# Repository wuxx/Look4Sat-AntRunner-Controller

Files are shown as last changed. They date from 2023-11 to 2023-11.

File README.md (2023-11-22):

# Look4Sat-AntRunner-Controller
 * [Introduce](#introduce)
 * [How to Use](#how-to-use)
 * [How to Compile](#how-to-compile)
 * [Rerfernce](#reference)

## Introduce
This project works as a component of my [AntRunner](https://github.com/wuxx/AntRunner) project to control my rotator wirelessly through the Look4Sat. Of course, if you have your own rotator that needs wireless control, this project should be helpful.

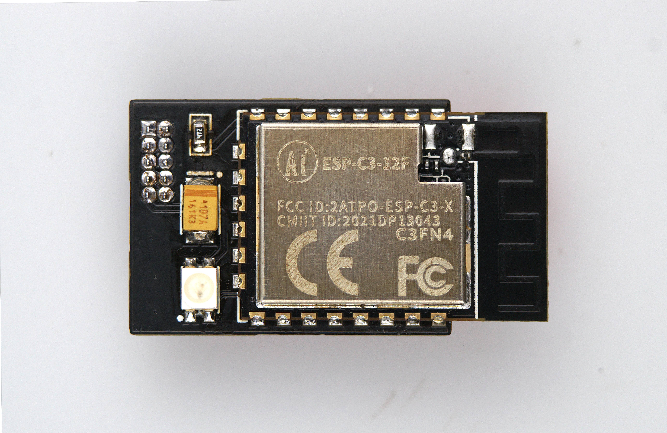
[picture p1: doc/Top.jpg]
top

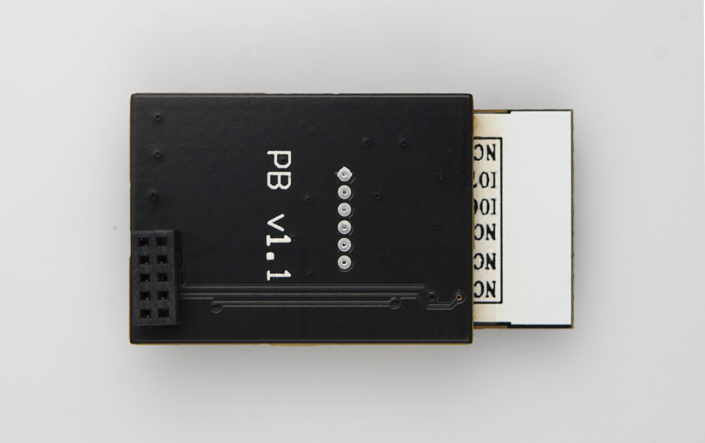
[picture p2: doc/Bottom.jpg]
bottom

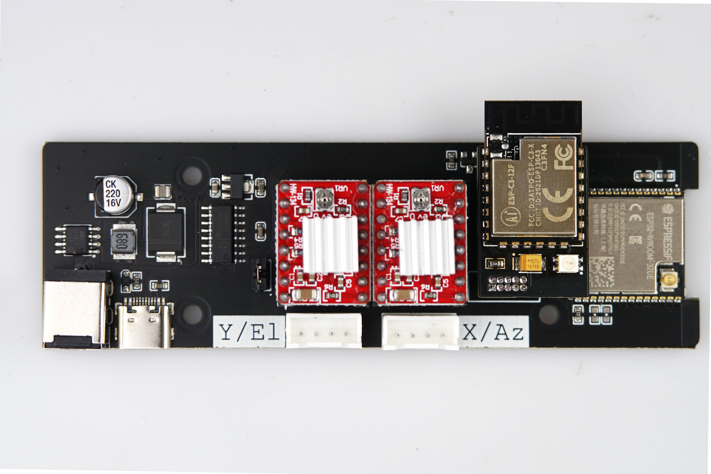
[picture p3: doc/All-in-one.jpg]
all-in-one


## How to Use

### Config the WiFi

Plug in the module on the AntRunner control board. After powering, a wifi hotspot called esp32 will appear. Click it to connect to this wifi hotspot (no password required).  
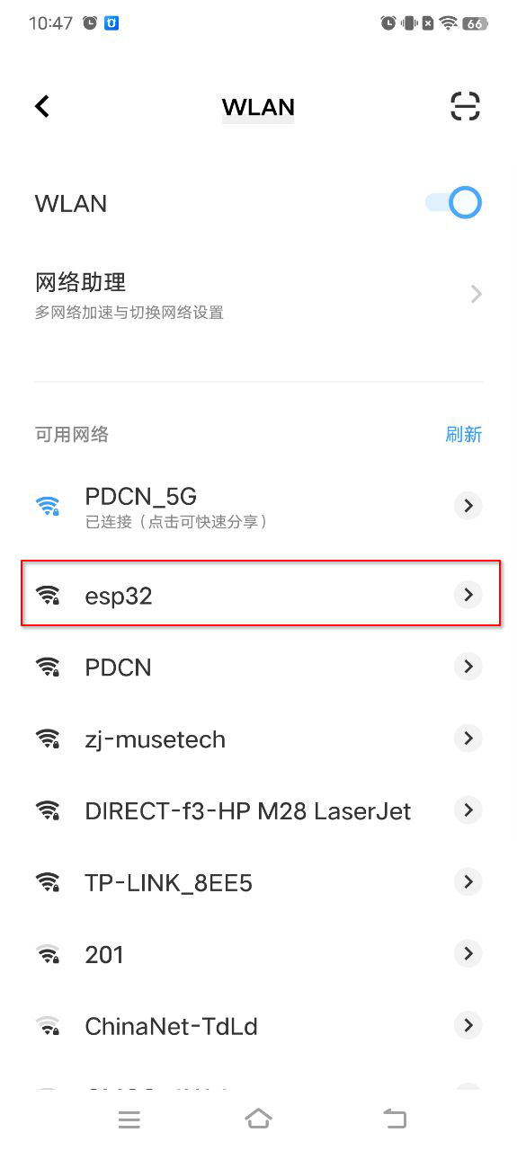
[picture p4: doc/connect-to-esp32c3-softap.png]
connect-to-esp32c3-softap


Then enter 10.10.10.1 in the browser to enter the operation background, select your wifi AP to connect. then the module will connect it in STA mode. After the connection is completed, you need to get the IP address, get it in the background of your WiFi AP or check the module's serial port output log.  
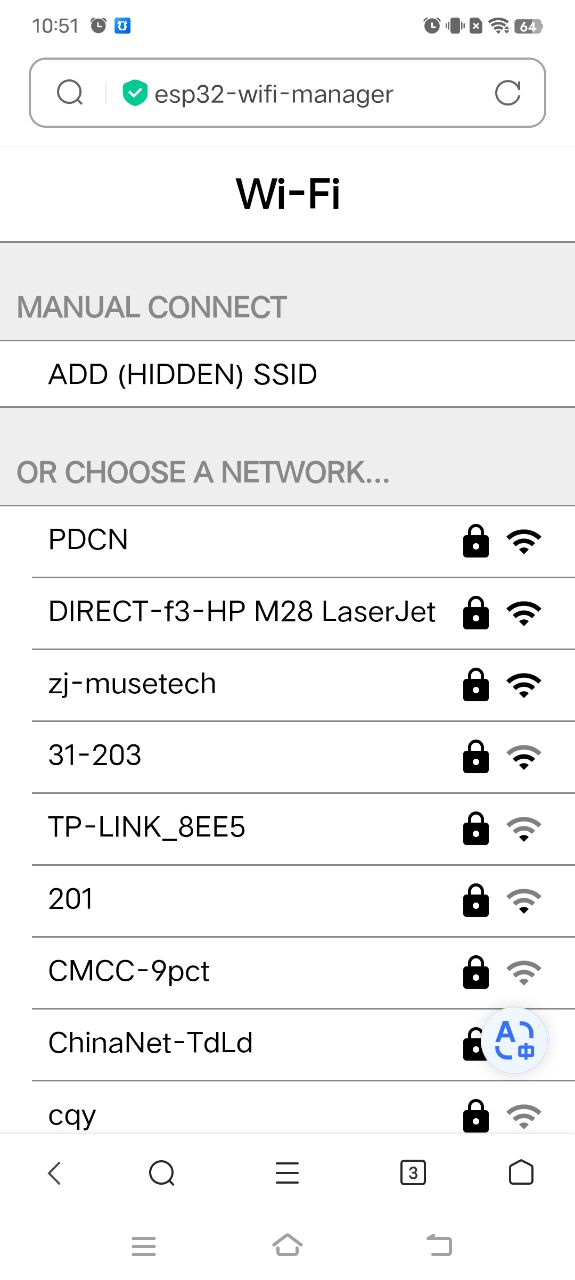
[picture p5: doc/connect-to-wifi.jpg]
connect-to-wifi


### Config the Look4Sat 

Open the configuration interface of Look4Sat, just fill in the IP address of module, and then the entire system can start working.   
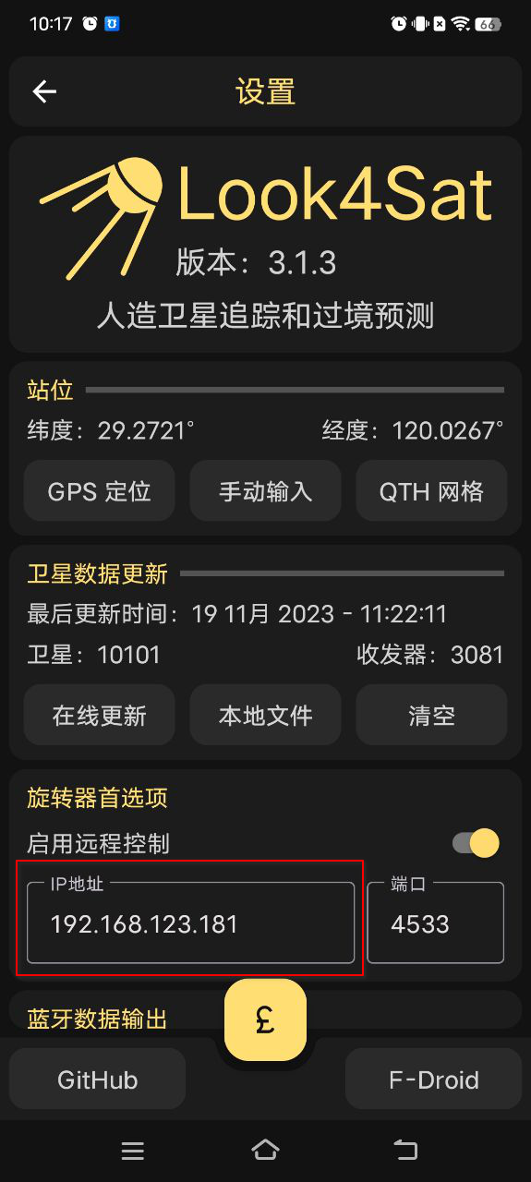
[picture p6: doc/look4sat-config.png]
look4sat-config


You can get the status of the current module by checking the LED lights. The details are as follows  

#### LED Status
LED | Description
---|---
Red light blink slowly | Connecting to wifi
Blue light always on| WiFi is connected
Green light always on | A connection has been established with Look4Sat
Green light blink quickly | Look4Sat is sending control commands

### Look4Sat Usage

The use of look4sat is very simple, just select a satellite entry and enter, look4sat will start sending control commands to the controller.  
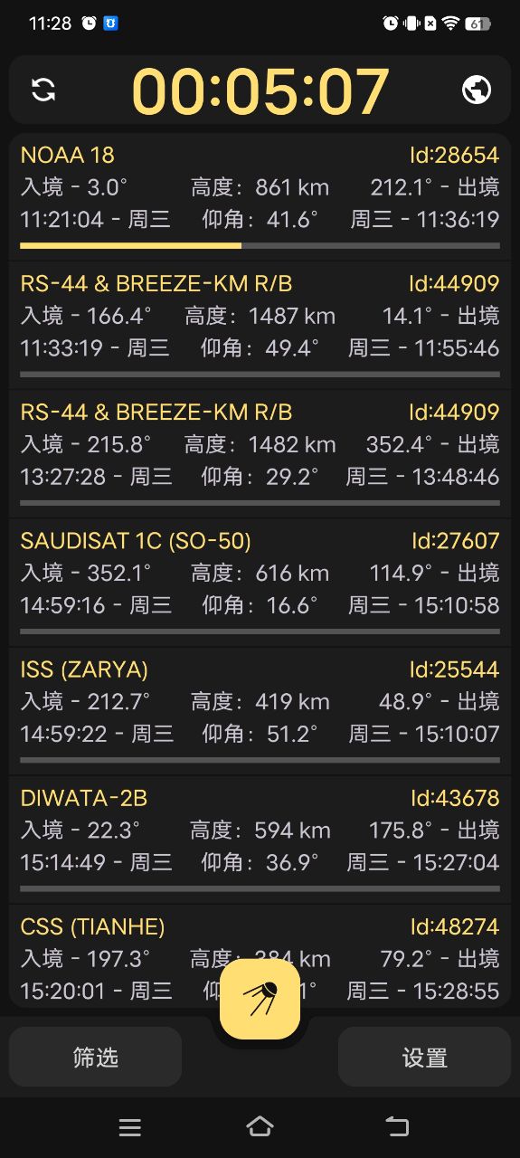
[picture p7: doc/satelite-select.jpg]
satelite-select

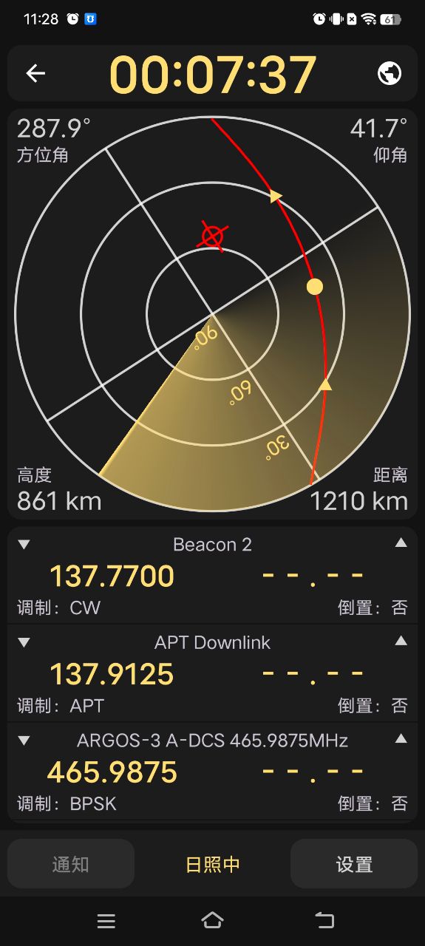
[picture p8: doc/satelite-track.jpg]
satelite-track


## How to Compile
the source code is compiled under esp-idf v5.1
```
$cd Look4Sat-AntRunner-Controller/software/
$cd ~/esp-idf && . ./export.sh && cd -
$idf.py set-target esp32c3
$idf.py build
$idf.py flash monitor
```

## Reference
- AntRunner (https://github.com/wuxx/AntRunner) 
- Look4Sat (https://github.com/rt-bishop/Look4Sat)

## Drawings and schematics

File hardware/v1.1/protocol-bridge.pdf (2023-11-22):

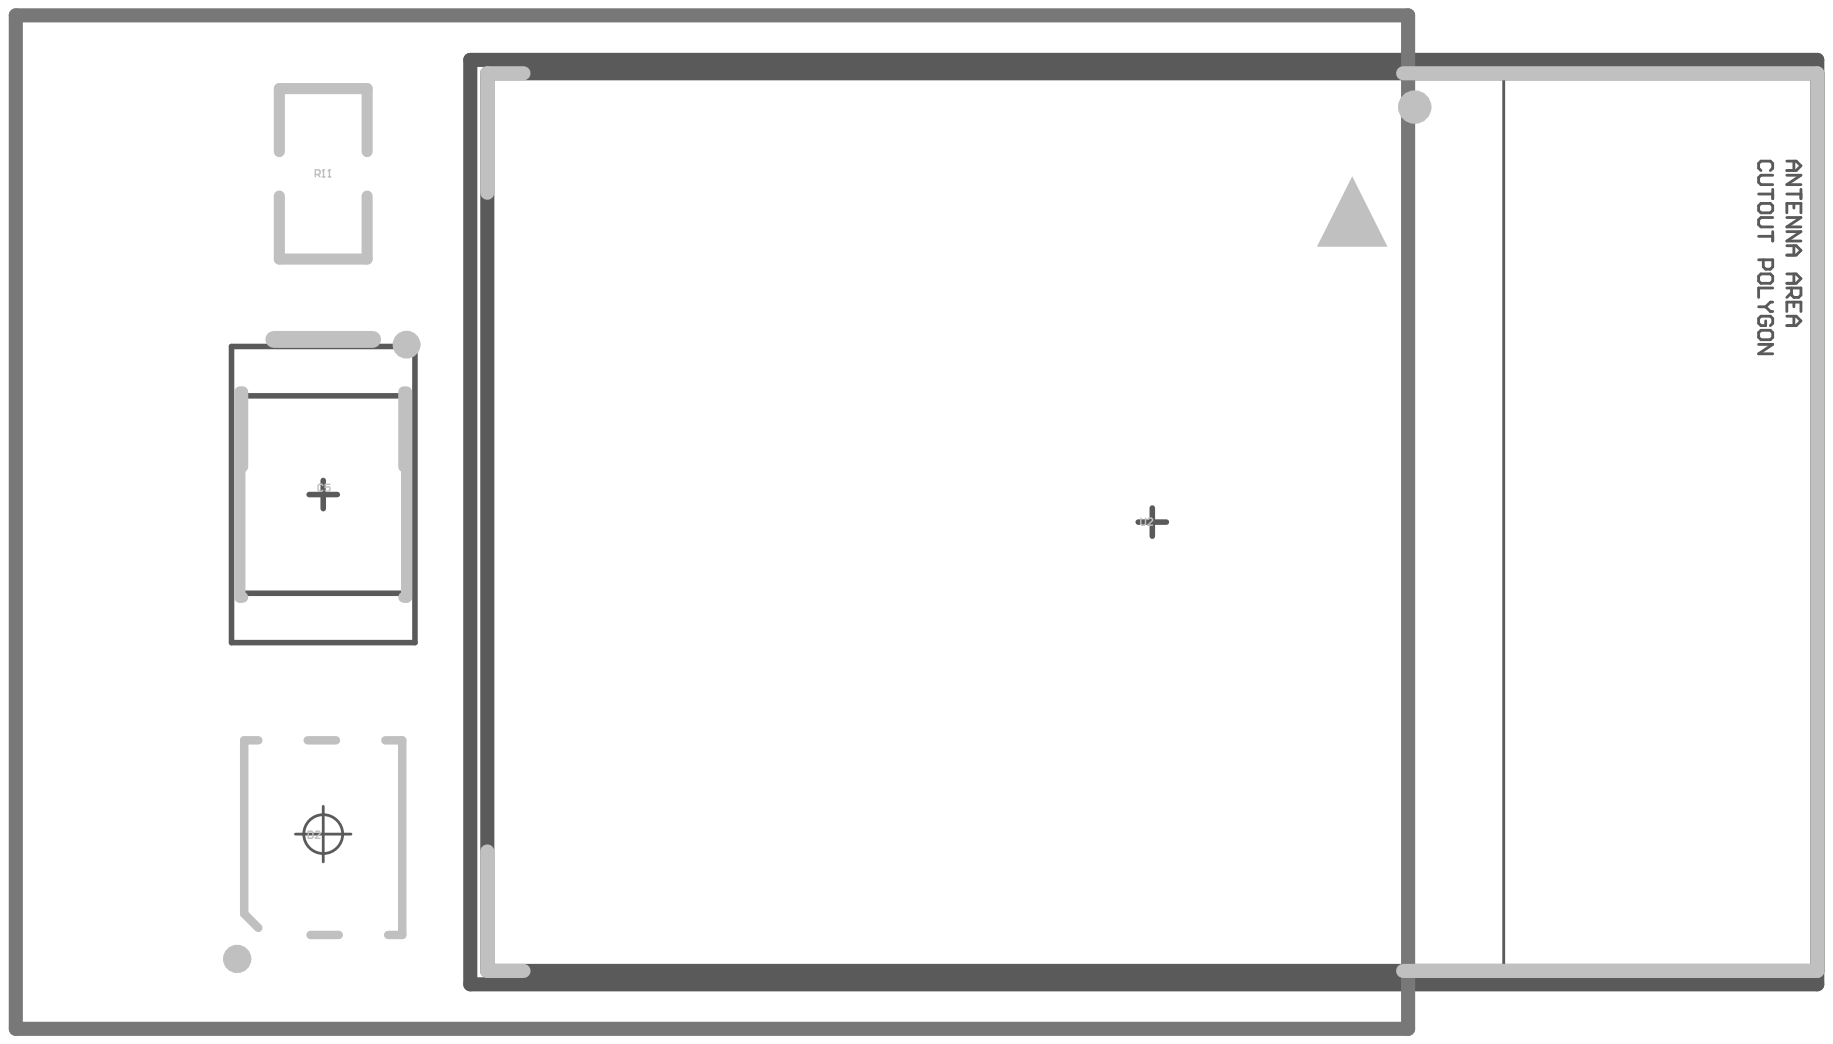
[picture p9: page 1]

Value | Comment | Designator | Footprint | Description | Quantity
| | J5 | HEADER_1.27_S MT_6x1 | Header, 4-Pin | 1
| 100uF | C5 | SMT_C_Tantalum _B | Capacitor, SM Tantalum; Body 3.5 x 2.8 mm (LxW typ) | 1
| ESP_C3_12F | U2 | ESP-C3-12F | ESP-12 Wi-Fi Module by AI-Thinker | 1
| Header 5X2 | J1 | HEAD_1.27_5x2 | Header, 5-Pin, Dual row | 1
| WS2812B | D2 | LED 3528-4Pin | | 1
4.7K | 4.7K | R11 | 0603_R | Resistor | 1

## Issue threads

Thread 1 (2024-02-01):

ESP32 download code

Montilien, 2024-02-01:
Hi,
Congratulations for your very nice work.
So I am familiar to load code to ESP32 using Arduino IDE but I not with ESP tools.
Please, can you write a step by step code downloading tutorial please?
An other problem for me, on module picture I can see 2 ESP32's modules. I don't understand why two esp32 are necessary to the rotator work?
Thanks for your response
Regards - F1FHK

Cyfarw9dd, 2024-08-07:
Hi,
This is BG2FZM, about load code using Arduino IDE. I'm afraid that this repository can only can run and flash on the esp-idf, which is a framework designed for the ESP chips for IOT functions, also more than that.
You can checkout this [tutorial](https://docs.espressif.com/projects/esp-idf/en/v5.3/esp32/get-started/index.html#installation) for further information. I recommend that you can use the vscode extension for the esp-idf and developing, which is more friendly and useful.
About the two chips, one is use for create a AP to let the other one and the mobile phone to check in, the other one running a tcp server to recviving the data from the Look4sat.
Hope it is useful
BG2FZM

wuxx, 2024-08-09:
Yes, in fact, one ESP chip can do all the work, but I don't want to modify the source code in GRBL, because the workload of modification may be relatively large, so this is a lazy solution

Cyfarw9dd, 2024-08-09:
maybe I will try，I've seen a stepper motor example using with DRV8825, providing by the esp idf offical example code. I currently try to work out this figure, still need more time XD.

> Yes, in fact, one ESP chip can do all the work, but I don't want to modify the source code in GRBL, because the workload of modification may be relatively large, so this is a lazy solution，may also be more flexible, because you can modify the source code yourself to adapt to other host software, and the source code will be simpler.

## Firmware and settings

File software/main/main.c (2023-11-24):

/* BSD Socket API Example

   This example code is in the Public Domain (or CC0 licensed, at your option.)

   Unless required by applicable law or agreed to in writing, this
   software is distributed on an "AS IS" BASIS, WITHOUT WARRANTIES OR
   CONDITIONS OF ANY KIND, either express or implied.
*/
#include <string.h>
#include <sys/param.h>
#include "freertos/FreeRTOS.h"
#include "freertos/task.h"
#include "esp_system.h"
#include "esp_wifi.h"
#include "esp_event.h"
#include "esp_log.h"
#include "nvs_flash.h"
#include "esp_netif.h"
#include <esp_ota_ops.h>
#include "esp_timer.h"

#include "esp_console.h"
#include "cmd_system.h"
#include "cmd_wifi.h"
#include "cmd_nvs.h"


//#include "protocol_examples_common.h"

#include "lwip/err.h"
#include "lwip/sockets.h"
#include "lwip/sys.h"
#include <lwip/netdb.h>

#include "wifi_manager.h"
#include "http_app.h"

#include "led_strip.h"

#include "driver/uart.h"

enum SYS_STATUS_E {

    WIFI_INIT = 0,
    WIFI_LOST,

    WIFI_CONNECTED,
    WIFI_IDLE,

    LOOK4SAT_CONNECTED,
    LOOK4SAT_IDLE,
    LOOK4SAT_XFER,
};

static uint32_t sys_status = WIFI_INIT;

int64_t last_xfer_systime = 0;
int64_t curr_systime = 0;

#define UART1_TXD    (0)
#define UART1_RXD    (1)
#define UART1_RTS    (UART_PIN_NO_CHANGE)
#define UART1_CTS    (UART_PIN_NO_CHANGE)
#define UART1_PORT_NUM      (1)
#define UART1_BAUD_RATE     (115200)

#define SERVER_PORT                 4533
#define KEEPALIVE_IDLE              5
#define KEEPALIVE_INTERVAL          5
#define KEEPALIVE_COUNT             3

#define ROTATOR_IP  "192.168.123.163"

//#define ROTATOR_CTRL_VIA_TELNET
//#define ROTATOR_CTRL_VIA_HTTP
#define ROTATOR_CTRL_VIA_UART

#define WEB_SERVER          ROTATOR_IP
#define ROTATOR_WEB_PORT    "80"
#define WEB_PATH_RESTART    "/command?commandText=[ESP444]RESTART"
#define WEB_PATH_PREFIX     "/command?commandText="


#define ROTATOR_TELNET_PORT (23)

#define TOLERANCE_DEFAULT  (5)

uint32_t TOLERANCE = TOLERANCE_DEFAULT;

#define RSIZE (1024)
// 42-gear-22
#define XDEGREE2MM(d)   ((d)/9.0)
#define YDEGREE2MM(d)   ((d)/9.0)

char *grbl_get_config = "$$\r\n";
char *grbl_get_pos = "?\r\n";

char *grbl_init_list[] =
{
    "$1=255\r\n",     /* lock motors */
    "$3=3\r\n",       /* invert X and Y direction */
    //"$100=80\r\n",    /* axis-x a4988   16 microstep */
    "$100=1776\r\n",  /* axis-x a4988   16 microstep 42-gear-motor-22-(1710/77) (80*1710)/77 */
    //"$101=160\n", /* axis-y drv8825 32 microstep */
    //"$101=80\n",  /* axis-y a4988   16 microstep */
    "$101=1776\r\n",  /* axis-y a4988   16 microstep 42-gear-motor-22-(1710/77) (80*1710)/77 */
    "$110=50\r\n",
    "$111=50\r\n",
    "$120=25\r\n",
    "$121=25\r\n",
    "G90\r\n",
    "G0 X0 Y0\r\n",
};

struct rot_req {
    float az;
    float el;
};

QueueHandle_t rot_req_queue;

static const char *TAG = "main";

static void look4sat_handler(const int sock)
{
    int len;
    char rx_buffer[128];

    struct rot_req *pr;

    float prev_az = 0, prev_el = 0;
    float curr_az = 0, curr_el = 0;

    float delta_az, delta_el;

    do {

        //sys_status = LOOK4SAT_IDLE;

        //curr_systime = esp_timer_get_time();
        //ESP_LOGE(TAG, "recv start");

        len = recv(sock, rx_buffer, sizeof(rx_buffer) - 1, 0);
        if (len < 0) {
            ESP_LOGE(TAG, "Error occurred during receiving: errno %d, reset rotator", errno);
            sys_status = WIFI_IDLE;
            pr = (struct rot_req *)malloc(sizeof(struct rot_req));
            pr->az = 0;
            pr->el = 0;
            xQueueSend(rot_req_queue, &pr, 0);
            prev_az = 0;
            prev_el = 0;

        } else if (len == 0) {
            ESP_LOGW(TAG, "Connection closed, reset rotator");
            sys_status = WIFI_IDLE;
            pr = (struct rot_req *)malloc(sizeof(struct rot_req));
            pr->az = 0;
            pr->el = 0;
            xQueueSend(rot_req_queue, &pr, 0);
            prev_az = 0;
            prev_el = 0;

        } else {
            rx_buffer[len] = 0; // Null-terminate whatever is received and treat it like a string
            ESP_LOGI(TAG, "Received %d bytes: [%s]", len, rx_buffer);

            sys_status = LOOK4SAT_XFER;

            last_xfer_systime = esp_timer_get_time();

            sscanf(rx_buffer, "\\set_pos %f %f", &curr_az, &curr_el);


            delta_az = curr_az > prev_az ? (curr_az - prev_az) : (prev_az - curr_az);
            delta_el = curr_el > prev_el ? (curr_el - prev_el) : (prev_el - curr_el);

            ESP_LOGI(TAG, "prev_az:  %.3f; prev_el:  %.3f", prev_az,  prev_el);
            ESP_LOGI(TAG, "curr_az:  %.3f; curr_el:  %.3f", curr_az,  curr_el);
            ESP_LOGI(TAG, "delta_az: %.3f; delta_el: %.3f", delta_az, delta_el);

#if 1
            if (curr_el >= 0 && prev_el >= 0) {
                if (delta_az >= TOLERANCE || delta_el >= TOLERANCE) {
                    ESP_LOGI(TAG, "send request to rot_req_queue");
                    pr = (struct rot_req *)malloc(sizeof(struct rot_req));
                    pr->az = curr_az;
                    pr->el = curr_el;
                    xQueueSend(rot_req_queue, &pr, 0);
                    prev_az = curr_az;
                    prev_el = curr_el;
                }

            }
#endif

#if 0
            // send() can return less bytes than supplied length.
            // Walk-around for robust implementation.
            int to_write = len;
            while (to_write > 0) {
                int written = send(sock, rx_buffer + (len - to_write), to_write, 0);
                if (written < 0) {
                    ESP_LOGE(TAG, "Error occurred during sending: errno %d", errno);
                }
                to_write -= written;
            }
#endif
        }
    } while (len > 0);
}

static void tcp_server_task(void *pvParameters)
{
    char addr_str[128];
    int addr_family = (int)pvParameters;
    int ip_protocol = 0;
    int keepAlive = 1;
    int keepIdle = KEEPALIVE_IDLE;
    int keepInterval = KEEPALIVE_INTERVAL;
    int keepCount = KEEPALIVE_COUNT;
    struct sockaddr_storage dest_addr;

    ESP_LOGE(TAG, "%s-%d", __func__, __LINE__);

    if (addr_family == AF_INET) {
        struct sockaddr_in *dest_addr_ip4 = (struct sockaddr_in *)&dest_addr;
        dest_addr_ip4->sin_addr.s_addr = htonl(INADDR_ANY);
        dest_addr_ip4->sin_family = AF_INET;
        dest_addr_ip4->sin_port = htons(SERVER_PORT);
        ip_protocol = IPPROTO_IP;
    }
#ifdef CONFIG_EXAMPLE_IPV6
    else if (addr_family == AF_INET6) {
        struct sockaddr_in6 *dest_addr_ip6 = (struct sockaddr_in6 *)&dest_addr;
        bzero(&dest_addr_ip6->sin6_addr.un, sizeof(dest_addr_ip6->sin6_addr.un));
        dest_addr_ip6->sin6_family = AF_INET6;
        dest_addr_ip6->sin6_port = htons(SERVER_PORT);
        ip_protocol = IPPROTO_IPV6;
    }
#endif

    int listen_sock = socket(addr_family, SOCK_STREAM, ip_protocol);
    if (listen_sock < 0) {
        ESP_LOGE(TAG, "Unable to create socket: errno %d", errno);
        vTaskDelete(NULL);
        return;
    }
    int opt = 1;
    setsockopt(listen_sock, SOL_SOCKET, SO_REUSEADDR, &opt, sizeof(opt));
#if defined(CONFIG_EXAMPLE_IPV4) && defined(CONFIG_EXAMPLE_IPV6)
    // Note that by default IPV6 binds to both protocols, it is must be disabled
    // if both protocols used at the same time (used in CI)
    setsockopt(listen_sock, IPPROTO_IPV6, IPV6_V6ONLY, &opt, sizeof(opt));
#endif

    ESP_LOGI(TAG, "Socket created");

    int err = bind(listen_sock, (struct sockaddr *)&dest_addr, sizeof(dest_addr));
    if (err != 0) {
        ESP_LOGE(TAG, "Socket unable to bind: errno %d", errno);
        ESP_LOGE(TAG, "IPPROTO: %d", addr_family);
        goto CLEAN_UP;
    }
    ESP_LOGI(TAG, "Socket bound, port %d", SERVER_PORT);

    err = listen(listen_sock, 1);
    if (err != 0) {
        ESP_LOGE(TAG, "Error occurred during listen: errno %d", errno);
        goto CLEAN_UP;
    }

    while (1) {

        ESP_LOGI(TAG, "Socket listening");

        struct sockaddr_storage source_addr; // Large enough for both IPv4 or IPv6
        socklen_t addr_len = sizeof(source_addr);
        int sock = accept(listen_sock, (struct sockaddr *)&source_addr, &addr_len);
        if (sock < 0) {
            ESP_LOGE(TAG, "Unable to accept connection: errno %d", errno);
            break;
        }

        // Set tcp keepalive option
        setsockopt(sock, SOL_SOCKET, SO_KEEPALIVE, &keepAlive, sizeof(int));
        setsockopt(sock, IPPROTO_TCP, TCP_KEEPIDLE, &keepIdle, sizeof(int));
        setsockopt(sock, IPPROTO_TCP, TCP_KEEPINTVL, &keepInterval, sizeof(int));
        setsockopt(sock, IPPROTO_TCP, TCP_KEEPCNT, &keepCount, sizeof(int));
        // Convert ip address to string
        if (source_addr.ss_family == PF_INET) {
            inet_ntoa_r(((struct sockaddr_in *)&source_addr)->sin_addr, addr_str, sizeof(addr_str) - 1);
        }
#ifdef CONFIG_EXAMPLE_IPV6
        else if (source_addr.ss_family == PF_INET6) {
            inet6_ntoa_r(((struct sockaddr_in6 *)&source_addr)->sin6_addr, addr_str, sizeof(addr_str) - 1);
        }
#endif
        ESP_LOGI(TAG, "Socket accepted ip address: %s", addr_str);
        sys_status = LOOK4SAT_CONNECTED;

        look4sat_handler(sock);

        shutdown(sock, 0);
        close(sock);
    }

CLEAN_UP:
    close(listen_sock);
    vTaskDelete(NULL);
}

int tcp_client_init(char *ip, uint16_t port)
{

    char addr_str[128];
    int addr_family;
    int ip_protocol;
    int sockfd = -1;
    int val = 1;
    int err;
    struct sockaddr_in dest_addr;

    dest_addr.sin_addr.s_addr = inet_addr(ip);
    dest_addr.sin_family = AF_INET;
    dest_addr.sin_port = htons(port);
    addr_family = AF_INET;
    ip_protocol = IPPROTO_IP;
    inet_ntoa_r(dest_addr.sin_addr, addr_str, sizeof(addr_str) - 1);

    ESP_LOGI(TAG, "%s start\r\n", __func__);

    sockfd = socket(addr_family, SOCK_STREAM, ip_protocol);
    if (sockfd < 0) {
        ESP_LOGE(TAG, "Unable to create socket: errno %d", errno);
        goto error;
    }

    ESP_LOGI(TAG, "Socket created, connecting to %s:%d", ip, port);

    err = connect(sockfd, (struct sockaddr *)&dest_addr, sizeof(dest_addr));
    if (err != 0) {
        ESP_LOGE(TAG, "Socket unable to connect: errno %d", errno);
        goto error;
    }


    setsockopt(sockfd, IPPROTO_TCP, TCP_NODELAY, (char *)&val, sizeof(val));

    ESP_LOGI(TAG, "Successfully connected to %d", port);
    return sockfd;

error:
    if (sockfd != -1) {
        ESP_LOGE(TAG, "Shutting down socket and restarting...");
        shutdown(sockfd, 0);
        close(sockfd);
    }
    return -1;
}

int rotator_request_http(int sockfd, char *request, uint32_t req_size, char *response, uint32_t *resp_size)
{

    const struct addrinfo hints = {
        .ai_family = AF_INET,
        .ai_socktype = SOCK_STREAM,
    };
    struct addrinfo *res;
    struct in_addr *addr;
    char request_get[256] = {0};
    char recv_buf[64];
    int s, r;

    int err = getaddrinfo(WEB_SERVER, ROTATOR_WEB_PORT, &hints, &res);

    if(err != 0 || res == NULL) {
        ESP_LOGE(TAG, "DNS lookup failed err=%d res=%p", err, res);
        vTaskDelay(1000 / portTICK_PERIOD_MS);
        return -1;
    }

    /* Code to print the resolved IP.

Note: inet_ntoa is non-reentrant, look at ipaddr_ntoa_r for "real" code */
    addr = &((struct sockaddr_in *)res->ai_addr)->sin_addr;
    ESP_LOGI(TAG, "DNS lookup succeeded. IP=%s", inet_ntoa(*addr));

    s = socket(res->ai_family, res->ai_socktype, 0);
    if(s < 0) {
        ESP_LOGE(TAG, "... Failed to allocate socket.");
        freeaddrinfo(res);
        vTaskDelay(1000 / portTICK_PERIOD_MS);
        return -1;
    }
    ESP_LOGI(TAG, "... allocated socket");

    if(connect(s, res->ai_addr, res->ai_addrlen) != 0) {
        ESP_LOGE(TAG, "... socket connect failed errno=%d", errno);
        close(s);
        freeaddrinfo(res);
        vTaskDelay(4000 / portTICK_PERIOD_MS);
        return -1;
    }

    ESP_LOGI(TAG, "... connected");
    freeaddrinfo(res);

    snprintf(request_get, sizeof(request_get), 
            "GET %s HTTP/1.0\r\nHost: %s:%s\r\nUser-Agent: esp-idf/1.0 esp32\r\n\r\n",
            request, ROTATOR_IP, ROTATOR_WEB_PORT);

    ESP_LOGI(TAG, "request_get: [%s]", request_get);

    if (write(s, request_get, strlen(request_get)) < 0) {

        ESP_LOGE(TAG, "... socket send failed");
        close(s);
        vTaskDelay(4000 / portTICK_PERIOD_MS);
        return -1;
    }
    ESP_LOGI(TAG, "... socket send success");

    struct timeval receiving_timeout;
    receiving_timeout.tv_sec = 5;
    receiving_timeout.tv_usec = 0;
    if (setsockopt(s, SOL_SOCKET, SO_RCVTIMEO, &receiving_timeout,
                sizeof(receiving_timeout)) < 0) {
        ESP_LOGE(TAG, "... failed to set socket receiving timeout");
        close(s);
        vTaskDelay(4000 / portTICK_PERIOD_MS);
        return -1;
    }
    ESP_LOGI(TAG, "... set socket receiving timeout success");

    /* Read HTTP response */
    do {
        bzero(recv_buf, sizeof(recv_buf));
        r = read(s, recv_buf, sizeof(recv_buf)-1);
        for(int i = 0; i < r; i++) {
            putchar(recv_buf[i]);
        }
    } while(r > 0);

    ESP_LOGI(TAG, "... done reading from socket. Last read return=%d errno=%d. (%s)", r, errno, strerror(errno));
    close(s);

    return 0;
}

int rotator_request_uart(int sockfd, char *request, uint32_t req_size, char *response, uint32_t *resp_size)
{

    int rlen;

    ESP_LOGE(TAG, "%s write [%s]", __func__, request);

    //uart_write_bytes(UART1_PORT_NUM, "hello\r\n", 7);

    uart_write_bytes(UART1_PORT_NUM, request, req_size);

    rlen = uart_read_bytes(UART1_PORT_NUM, response, 1024, pdMS_TO_TICKS(100)); /* 100ms */
    ESP_LOGE(TAG, "%s read [%s]", __func__, response);

    return 0;
}

int rotator_request_telnet(int sockfd, char *request, uint32_t req_size, char *response, uint32_t *resp_size)
{
    int err, rsize;

    err = send(sockfd, request, req_size, 0);
    if (err < 0) {
        ESP_LOGE(TAG, "Error occurred during sending: errno %d", errno);
        goto error;
    }

    vTaskDelay(pdMS_TO_TICKS(100));

    rsize = recv(sockfd, response, 1024, 0);
    if (rsize < 0) {
        ESP_LOGE(TAG, "Error occurred during recving: errno %d (%s)", errno, strerror(errno));
        goto error;
    }

    ESP_LOGI(TAG, "req: [%s]; resp: [%s]", request, response);

    *resp_size = rsize;

    return 0;

error:
    return -1;

}


int rotator_init_telnet(int rot_fd)
{
    int i, retval;
    uint32_t init_count;
    char rsp[RSIZE] = {0};
    uint32_t resp_size;

    rotator_request_telnet(rot_fd, grbl_get_config, strlen(grbl_get_config), rsp, &resp_size);

    if (strstr(rsp, grbl_init_list[0]) != NULL)
    {
        ESP_LOGI(TAG, "rotator already configured");
        return 0;
    }

    init_count = sizeof(grbl_init_list) / sizeof(grbl_init_list[0]);

    for (i = 0; i < init_count; i++)
    {
        ESP_LOGI(TAG, "rotator_request [%s] ", grbl_init_list[i]);
        memset(rsp, 0, sizeof(rsp));
        retval = rotator_request_telnet(rot_fd, grbl_init_list[i], strlen(grbl_init_list[i]), rsp,
                &resp_size);

        //fprintf(stderr, "done\n");
        if (retval != 0)
        {
            ESP_LOGE(TAG, "rotator_request [%s] fail\n", grbl_init_list[i]);
            return -1;
        }
    }

    return 0;

}

int rotator_set_position(int rot_fd, float curr_az, float curr_el)
{
    int i;
    int retval;
    static float prev_az, prev_el;

    static float prev_x, curr_x;
    float x[3], delta[3];

    float y;

    char req[RSIZE] = {0};
    char rsp[RSIZE] = {0};
    uint32_t rsp_size;

    float min_value;
    int   min_index;

    /* az:x: 0 - 360 */
    /* el:y: 0 - 90 */
#if 1
    ESP_LOGI(TAG,
              "%s: (prev_x) = (%.3f); (prev_az) = (%.3f); (prev_el) = (%.3f); (curr_az, curr_el) = (%.3f, %.3f)\n",
              __func__, prev_x, prev_az, prev_el, curr_az, curr_el);
#endif

    /* convert degree to mm, 360 degree = 40mm, 1 degree = 0.111mm */
    //x = az * 0.111;
    //y = el * 0.111;

    /* 360 -> 0 */
    if ((prev_az > 270 && prev_az < 360) && (curr_az > 0 && curr_az < 90)) {

        ESP_LOGI(TAG, "%s:%d\n", __func__, __LINE__);

        if (prev_x >= XDEGREE2MM(270))
        {   /* 在顺时针第一圈里，平滑越过第一圈，到顺时针第二圈，如果是顺时针第二圈的时候，还是返回到第一圈内 */
            curr_x = XDEGREE2MM(curr_az) + XDEGREE2MM(360);
        } else {   /* prev_x 也可能为负值(逆时针第一圈或者第二圈)，这个时候重新回到第一圈内 */
            curr_x = XDEGREE2MM(curr_az);
        }

      /* 0 -> 360 */  
    } else if ((prev_az > 0   && prev_az < 90) &&
             (curr_az > 270 && curr_az < 360)) {
        ESP_LOGI(TAG, "%s:%d\n", __func__, __LINE__);


        if (prev_x >= XDEGREE2MM(360)) {
            /* 已经在顺时针第二圈里了，回到第一圈里 */
            curr_x = XDEGREE2MM(curr_az);
        } else {
            /* 在顺时针第一圈里，则直接到逆时针第一圈 */
            /* 或者在逆时针第一圈里，也是直接回到逆时针第一圈里 */
            curr_x = XDEGREE2MM(curr_az) - XDEGREE2MM(360); /* 是个负数 */
        }

        /* reset */
    } else if (curr_az == 0 && curr_el == 0) {
        ESP_LOGI(TAG,  "%s: reset\n", __func__);
        curr_x = 0;
        y = 0;
    } else {
        ESP_LOGI(TAG, "%s-%d prev_x: %.3f\n", __func__, __LINE__, prev_x);

        /* 某个位置可能处于三圈中的某一圈，选择和其最近的一个值 */
        x[0] = XDEGREE2MM(curr_az) - XDEGREE2MM(360);
        x[1] = XDEGREE2MM(curr_az);
        x[2] = XDEGREE2MM(curr_az) + XDEGREE2MM(360);

        delta[0] = prev_x - x[0];
        delta[1] = prev_x - x[1];
        delta[2] = prev_x - x[2];

        /* convert to absolute value, then compare the minimum distance */
        if (delta[0] < 0) { delta[0] = -1 * delta[0]; }

        if (delta[1] < 0) { delta[1] = -1 * delta[1]; }

        if (delta[2] < 0) { delta[2] = -1 * delta[2]; }

        min_value = delta[0];
        min_index = 0;

        for (i = 0; i < 3; i++) {
            if (delta[i] <= min_value)
            {
                min_value = delta[i];
                min_index = i;
            }
        }

        curr_x = x[min_index];
        ESP_LOGI(TAG, "min_index: %d; curr_x: %.3f\n", min_index, curr_x);
    }

    y = YDEGREE2MM(curr_el);
    /**/
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
void app_main(void)
{
#if 0
    ESP_ERROR_CHECK(nvs_flash_init());
    ESP_ERROR_CHECK(esp_netif_init());
    ESP_ERROR_CHECK(esp_event_loop_create_default());

    /* This helper function configures Wi-Fi or Ethernet, as selected in menuconfig.
     * Read "Establishing Wi-Fi or Ethernet Connection" section in
     * examples/protocols/README.md for more information about this function.
     */
    ESP_ERROR_CHECK(example_connect());
#endif

    /* start the wifi manager */

    ESP_LOGE(TAG, "%s\r\n", sys_banner);

    led_init();

    wifi_manager_start();

    /* register a callback as an example to how you can integrate your code with the wifi manager */
    wifi_manager_set_callback(WM_EVENT_STA_GOT_IP, &cb_connection_ok);

    wifi_manager_set_callback(WM_EVENT_STA_DISCONNECTED, &cb_sta_disconnect);

    //http_app_set_handler_hook(HTTP_GET,  &my_get_handler);
    //http_app_set_handler_hook(HTTP_POST, &my_post_handler);


#ifdef ROTATOR_CTRL_VIA_UART
    uart_config_t uart_config = {
         .baud_rate = UART1_BAUD_RATE,
         .data_bits = UART_DATA_8_BITS,
         .parity    = UART_PARITY_DISABLE,
         .stop_bits = UART_STOP_BITS_1,
         .flow_ctrl = UART_HW_FLOWCTRL_DISABLE,
         .source_clk = UART_SCLK_APB,
     };
     int intr_alloc_flags = 0;

#if CONFIG_UART_ISR_IN_IRAM
    intr_alloc_flags = ESP_INTR_FLAG_IRAM;
#endif


    ESP_ERROR_CHECK(uart_driver_install(UART1_PORT_NUM, 2048, 0, 0, NULL, intr_alloc_flags));
    ESP_ERROR_CHECK(uart_param_config(UART1_PORT_NUM, &uart_config));
    ESP_ERROR_CHECK(uart_set_pin(UART1_PORT_NUM, UART1_TXD, UART1_RXD, UART1_RTS, UART1_CTS));

    rotator_init();

    //uart_write_bytes(UART1_PORT_NUM, "hello\r\n", 7);

    ESP_LOGE(TAG, "test start");

    /* test */
    snprintf(req, sizeof(req), "$$\r\n");
    ESP_LOGE(TAG, "%s write [%s]", __func__, req);
    rotator_request_uart(0, req, strlen(req), rsp, &rsp_size);
    ESP_LOGE(TAG, "%s read [%s]", __func__, rsp);

    //rotator_set_position(0, 45, 45);

    ESP_LOGE(TAG, "test end");

#endif

 
    rot_req_queue = xQueueCreate(256, sizeof(struct rot_req *));

#define CONFIG_EXAMPLE_IPV4

#ifdef CONFIG_EXAMPLE_IPV4
    xTaskCreate(tcp_server_task, "tcp_server", 4096, (void*)AF_INET, 5, NULL);
#endif

#ifdef CONFIG_EXAMPLE_IPV6
    xTaskCreate(tcp_server_task, "tcp_server", 4096, (void*)AF_INET6, 5, NULL);
#endif

    ESP_LOGE(TAG, "%s-%d", __func__, __LINE__);
    xTaskCreate(rotator_ctrl_task, "rotator_ctrl", 8192, NULL, 5, NULL);

    //uint32_t ota_mode = 0;
    //xTaskCreate(ota_task, "ota_task", 4096, &ota_mode, 5, NULL);

    console_start();

    while (1) {

        switch (sys_status) {
            case (WIFI_INIT):
            case (WIFI_LOST):
                led_toggle(LED_COLOR_RED);
                vTaskDelay(pdMS_TO_TICKS(1000));
                break;
            case (WIFI_CONNECTED):
            case (WIFI_IDLE):
                led_on(LED_COLOR_BLUE);
                vTaskDelay(pdMS_TO_TICKS(100));
                break;
            case (LOOK4SAT_CONNECTED):
            case (LOOK4SAT_IDLE):
                led_on(LED_COLOR_GREEN);
                vTaskDelay(pdMS_TO_TICKS(100));
                break;
            case (LOOK4SAT_XFER):
                led_toggle(LED_COLOR_GREEN);
                vTaskDelay(pdMS_TO_TICKS(200));

                curr_systime = esp_timer_get_time();

                /* 500ms auto timeout state transition */
                if ((curr_systime - last_xfer_systime) > 500000) {
                    if (sys_status == LOOK4SAT_XFER) {
                        sys_status = LOOK4SAT_IDLE;
                    }

                }

                break;
            default:
                ESP_LOGE(TAG, "unknown sys_status: %ld\r\n", sys_status);
                vTaskDelay(pdMS_TO_TICKS(1000));
                break;
        }


    }

}

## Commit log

2023-11-22 On branch master
    Initial commit
    Changes to be committed:
    new file: README.md
    new file: firmware/bootloader.bin
    new file: firmware/flash_write.sh
    new file: firmware/partition-table.bin
    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
2023-11-22 On branch master Your branch is up to date with 'origin/master'.
    new file: v1.1/.gitignore
    new file: v1.1/Free Documents.OutJob
    new file: v1.1/__Previews/protocol-bridge.SchDocPreview
    new file: v1.1/protocol-bridge.OutJob
    new file: v1.1/protocol-bridge.PcbDoc
    new file: v1.1/protocol-bridge.PcbLib
    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
    [protocol-bridge.PcbDoc, protocol-bridge.PrjPcb, protocol-bridge.SCHLIB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]
2023-11-22 On branch master Your branch is up to date with 'origin/master'.
    modified: README.md
    new file: doc/connect-to-esp32c3-softap.png
    new file: doc/connect-to-wifi.jpg
    new file: doc/look4sat-config.png
    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
2023-11-22 On branch master Your branch is up to date with 'origin/master'.
    On branch master
    Your branch is up to date with 'origin/master'.
    new file: doc/satelite-select.jpg
    new file: doc/satelite-track.jpg
    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
2023-11-24 code bugfix. On branch master Your branch is up to date with 'origin/master'.
    new file: firmware/flash_erase.sh
    modified: firmware/protocol-bridge.bin
    modified: software/main/main.c
    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
    [main.c]
